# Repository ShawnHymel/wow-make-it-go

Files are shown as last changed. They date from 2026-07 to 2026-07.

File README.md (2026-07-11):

# WOW Make It Go

Pinewood derby style track timer for the "Make It Go" exhibit at the [WOW Children's Museum](https://wowchildrensmuseum.org/).

## Hardware

Each track uses its own full setup (i.e. separate Arduino, sensors, etc.). The track timers do not talk to each other. Each track requires:

 * [Arduino UNO R3](https://store-usa.arduino.cc/products/arduino-uno-rev3) or [SparkFun RedBoard](https://www.sparkfun.com/sparkfun-redboard-programmed-with-arduino.html)
 * [SparkFun Qwiic Shield](https://www.sparkfun.com/catalogsearch/result/?q=proto+shield)
 * 2x [SparkFun Proximity Sensor Breakout](https://www.sparkfun.com/sparkfun-proximity-sensor-breakout-20cm-vcnl4040-qwiic.html)
 * [SparkFun 7-Segment Serial Display - Red](https://www.sparkfun.com/sparkfun-7-segment-serial-display-red.html)
 * 2x [SparkFun QwiicBus EndPoint](https://www.sparkfun.com/sparkfun-qwiicbus-endpoint.html)
 * 2x [RJ45 Female Connector Breakout](https://www.amazon.com/Cermant-RJ45-Single-Connector-Interface/dp/B0D7ZZQ8CJ/)
 * [CAT6 Patch Cable 15 ft](https://www.amazon.com/Amazon-Basics-Ethernet-High-Speed-Snagless/dp/B089MGH8W3/)
 * [CAT6 Patch Cable 6 ft](https://www.amazon.com/Cable-Matters-Ethernet-Patch-Black/dp/B0CP9XGZKM/)
 * USB Cable 15 ft ([Type-B](https://www.amazon.com/Monoprice-15-Feet-24AWG-Plated-105440/dp/B003L11CRU/) for UNO R3, [Mini-B](https://www.amazon.com/Monoprice-15-Feet-Mini-B-Ferrite-105450/dp/B002KL8N6A/) for RedBoard)
 * [USB power adapter](https://www.amazon.com/Charger-Adapter-Charging-Station-Samsung/dp/B08139YF93/)

## Connections

TODO: fill this out. For now, refer to the connections in the Arduino sketch

## Programming

Load the [track_timer](software\track_timer\track_timer.ino) sketch in Arduino. Upload it to the Arduino board.

## License

All software in this repository, unless otherwise noted, is licensed under the [Zero-Clause BSD](https://opensource.org/license/0bsd) license.

```
Permission to use, copy, modify, and/or distribute this software for
any purpose with or without fee is hereby granted.

THE SOFTWARE IS PROVIDED “AS IS” AND THE AUTHOR DISCLAIMS ALL
WARRANTIES WITH REGARD TO THIS SOFTWARE INCLUDING ALL IMPLIED WARRANTIES
OF MERCHANTABILITY AND FITNESS. IN NO EVENT SHALL THE AUTHOR BE LIABLE
FOR ANY SPECIAL, DIRECT, INDIRECT, OR CONSEQUENTIAL DAMAGES OR ANY
DAMAGES WHATSOEVER RESULTING FROM LOSS OF USE, DATA OR PROFITS, WHETHER IN
AN ACTION OF CONTRACT, NEGLIGENCE OR OTHER TORTIOUS ACTION, ARISING OUT
OF OR IN CONNECTION WITH THE USE OR PERFORMANCE OF THIS SOFTWARE.
```

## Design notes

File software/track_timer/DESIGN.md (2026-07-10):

# Track Timer — design notes

Non-blocking gravity-track timer: an object rests on a start gate (sensor 1),
is released, rolls, and trips a finish line (sensor 2). Two VCNL4040 proximity
sensors, one SparkFun serial 4-digit 7-segment display.

## Display format

`SSS.C` — seconds with one tenth (decimal point after digit 3, `DP3`).
The ones-of-seconds digit is always drawn, so zero reads `0.0`, not `.0`.
Range spans to 999.9 s, which is also the timeout ceiling below.

## Sensing

Neither sensor has a fixed trigger level. `setup()` averages
`AMBIENT_SAMPLES` (10) readings from each sensor with the track clear, stores
them as `ambient1` / `ambient2`, and thereafter treats
`ambient + TRIGGER_DELTA` (500) as "covered". This is why the track must be
empty at boot.

`checkTrigger()` applies 50 counts of hysteresis: a sensor that has fired
re-arms only once its reading falls back below `threshold - 50`, so a hovering
hand cannot machine-gun triggers.

## State machine

Everything is driven by `millis()` and the sensors' own edge/level state —
no `delay()`, no blocking.

| State | Display | Exit condition | Next |
|---|---|---|---|
| `READY` | `0.0` at boot, else last result  | object placed on gate (sensor 1 rising edge) | `PRIMED` |
| `PRIMED` | steady `-GO-` | object leaves gate (sensor 1 falling edge) | `RUNNING`  |
| `RUNNING`  | live time | finish line (sensor 2 rising edge) | `FINISHED` |
| `RUNNING`  | live time | 999.9 s timeout | `READY` |
| `FINISHED` | final time, flashing then held | `FINISH_FLASH_COUNT` flashes elapsed | `READY` |
| `ERROR` | `Err1` / `Err2` | both sensors read OK again | `READY` |

- `READY` doubles as the post-race state: the final time stays frozen on the
  display until a new object re-primes the gate (that is the "reset").
- `FINISHED` blinks the result `FINISH_FLASH_COUNT` (4) times, toggling every
  `FINISH_FLASH_MS` (300 ms) and starting from blank — about 2.4 s — then holds
  the time and drops to `READY`.
- A sensor 1 rising edge re-primes from **any** state except `ERROR`, not just
  from `READY`. Re-staging an object on the gate mid-race abandons the run in
  progress rather than waiting for the timeout.
- Timeout freezes the display at the 999.9 s ceiling and returns to `READY`;
  it is not treated as an error and does not flash.

### Both sensors are polled every pass

`loop()` calls `checkTrigger()` on both sensors unconditionally — that call is
what refreshes each sensor's `ok()` and `covered()` state, so it cannot be
skipped. What is state-dependent is whether the returned edge is *consumed*:
sensor 2's rising edge is only acted on in `RUNNING`.

An edge raised outside `RUNNING` is therefore discarded, and — because of the
hysteresis above — that sensor stays latched `covered` until it re-arms. An
object left sitting on the finish line before the race starts will not produce
a finish trigger when the race runs; it has to be lifted clear first.

### Errors

A failed read on either sensor (`READ_ERROR` = `0xFFFF`) puts the machine in
`ERROR` immediately, from any state, and `loop()` returns early. Recovery — one
pass where both sensors read cleanly — resets to `READY` and clears the display
to `0.0`, so an error mid-race loses that run's time. `prevCovered1` is
resynced on the way out so the recovery does not fire a phantom release edge.

`ERROR_REBOOT_LIMIT` (10) *consecutive* failed passes on either sensor calls
`hardReboot()`. The per-sensor counters reset on any fully clean pass. Note
that a pass costs single-digit milliseconds, so ten of them go by fast: in
practice `Err1` / `Err2` flickers rather than sits on the display before the
reboot. Raise the limit if you want the code readable by a human on the bench.

`hardReboot()` arms the watchdog at its shortest timeout (15 ms) and spins,
which resets registers and peripherals too — unlike a jump-to-zero soft reset.

## Watchdog

`wdt_enable(WDTO_1S)` at the end of `setup()`, `wdt_reset()` at the top of
`loop()`. Three things about the placement are load-bearing:

- **Armed last, not first.** `setup()` blocks for >2 s (two settle delays plus
  `AMBIENT_SAMPLES * 50 ms` of calibration). Arming before that resets us
  mid-calibration, forever.
- **Fed at the top of `loop()`, not the bottom.** The `ERROR` branch `return`s
  early. A feed at the bottom would be skipped on every failed read, letting
  the watchdog pre-empt the `ERROR_REBOOT_LIMIT` path that is supposed to own
  that reboot (and its `Err1` / `Err2` display).
- **`MCUSR` / `WDRF` cleared first.** After a watchdog reset the WDT is still
  armed; `WDRF` must be cleared before `WDE` can be. Optiboot does this before
  handing over — ours is belt-and-braces, and would not save a stock bootloader
  (that one gets reset inside its own startup delay, before `setup()` runs).

It exists to catch one thing the `ERROR` state cannot. The AVR `Wire` library
spins with **no timeout** in `endTransmission()` / `requestFrom()`, so a
finish-line VCNL4040 that wedges SDA low hangs `loop()` forever, with no failed
read to count. This is accepted as-is rather than fixed in the driver: it is
unlikely, and a bounded TWI implementation is a lot of code to own. The
watchdog is the cheap backstop.

`SoftVCNL4040::sclHighWait()` already bounds its own spin at 1000 µs, so the
bit-banged start gate degrades into `READ_ERROR` and the `ERROR` state instead
of hanging — it never needed the watchdog.

`hardReboot()` is unaffected: `wdt_enable()` performs the WDCE/WDE timed
sequence, so re-arming a running 1 s watchdog down to 15 ms is legal.

## Bus layout

Both VCNL4040s answer to I2C address `0x60`, so they can't share a bus.
Each sensor gets its own:

- **Sensor 1 (start gate)** — bit-banged software I2C (`SoftVCNL4040`) on
  SDA pin 2 / SCL pin 5.
- **Sensor 2 (finish line)** — hardware I2C (`HardVCNL4040`, the `Wire`
  library) on the ATmega's fixed TWI pins A4 (SDA) / A5 (SCL).

Both drivers expose the same API (`begin` / `checkTrigger` / `ok` / `covered` /
`last`), so the state machine treats the two sensors identically.

The VCNL4040 is a 3.3 V part and both breakouts carry 2.2 kΩ pull-ups to 3.3 V,
so neither driver may enable the AVR's internal pull-ups. `SoftVCNL4040`
emulates open-drain by hand (drive low, or release to float).
`HardVCNL4040::begin()` has to actively switch them back off, because
`Wire.begin()` turns them on.

## Driver support (`SoftVCNL4040.h` / `HardVCNL4040.h`)

Three small additions so the sketch can see gate edges and read failures:

- `checkTrigger()` ignores a failed read (`READ_ERROR` = `0xFFFF`) instead of
  treating it as a huge value and firing a phantom trigger.
- `covered()` — debounced presence level, used to detect the *release*
  (falling) edge of the start gate.
- `ok()` — `_last != READ_ERROR`, drives the `ERROR` state.

## Display driver (`Serial7Seg.h`)

Unchanged. The sketch only pushes over SPI when the shown content changes:
`showTenths()` caches the last numeric value, `showText()` handles
`-GO-` / errors / blank, and `showMode` tracks which of the two is on screen so
the decimal point is toggled only on an actual number↔text transition.

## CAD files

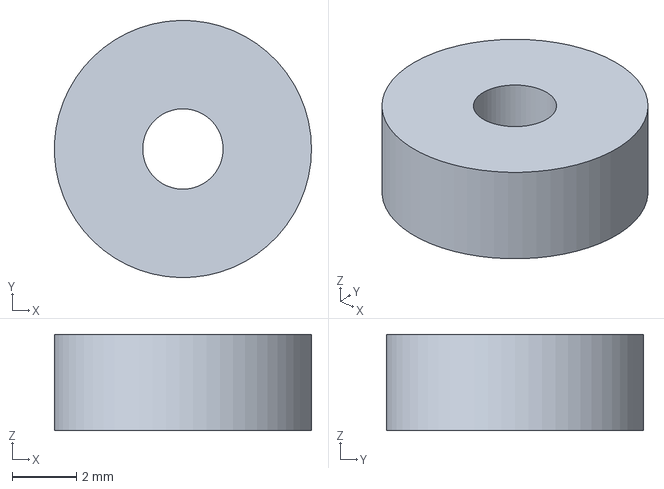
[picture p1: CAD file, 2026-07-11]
mechanical/prox-sensor-washer.FCStd
7.99 x 8.00 x 3.00 mm

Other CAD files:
mechanical/prox-sensor-washer.stl

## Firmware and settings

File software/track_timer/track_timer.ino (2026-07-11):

// Arduino libraries
#include <SPI.h>
#include <avr/wdt.h>

// Custom libraries
#include "SoftVCNL4040.h"
#include "HardVCNL4040.h"
#include "Serial7Seg.h"

//*****************************************************************************
// Settings

// Set to 1 to stream both sensors' raw readings over serial every loop pass.
// Leave at 0 for normal operation.
#define DEBUG 0

const uint16_t TRIGGER_DELTA     = 500;   // how far above ambient = "covered"
const uint8_t  AMBIENT_SAMPLES   = 10;    // readings to average during calibration

const uint8_t  DISPLAY_SS_PIN    = 8;
const uint8_t  DISPLAY_BRIGHTNESS = 255;

// A run that never trips the finish line is abandoned here. The timer
// freezes at the ceiling and the display returns to READY.
const unsigned long RACE_TIMEOUT_MS = 999900UL;   // 999.9 s

// Finish-line time flash: blink the result this many times before holding.
const uint8_t      FINISH_FLASH_COUNT = 4;
const unsigned long FINISH_FLASH_MS   = 300UL;

// Consecutive read failures before a hard reboot.
const uint8_t ERROR_REBOOT_LIMIT = 10;

// Watchdog timeout. A normal loop() pass is a few milliseconds -- two sensor
// reads and at most one SPI write -- so a second leaves enormous headroom
// while still recovering faster than a spectator can register the freeze.
const uint8_t WDT_TIMEOUT = WDTO_1S;

//*****************************************************************************
// Globals

// Both VCNL4040s answer to I2C address 0x60, so they can't share a bus.
// We split them across two buses instead: the start gate is bit-banged on
// its own SDA/SCL pins, and the finish line owns the ATmega's dedicated
// hardware-I2C pins (A4 = SDA, A5 = SCL). One sensor per bus, no clash.
SoftVCNL4040 prox1(2, 5);  // bit-banged SDA 2 / SCL 5 -- start gate
HardVCNL4040 prox2;         // hardware I2C on A4/A5    -- finish line

// 7-segment LED display
Serial7Seg display(DISPLAY_SS_PIN);

// Proximity sensor ambient baselines (captured during setup)
uint16_t ambient1 = 0;
uint16_t ambient2 = 0;


//*****************************************************************************
// Timer state machine
//
//   READY    -- idle. Display holds 0.0 (boot) or the last race time until a
//               new object is placed on the start gate.
//   PRIMED   -- object resting on the gate. Show steady "GO" until released.
//   RUNNING  -- object has left the gate; count up live. Stop on the finish
//               line (sensor 2) or at the timeout ceiling.
//   FINISHED -- finish line tripped; flash the final time a few times, then
//               hold it and return to READY.
//   ERROR    -- a sensor read failed; show Err1/Err2 until it recovers.
//
// Nothing here blocks: every transition is driven by millis() and the
// sensors' own edge/level state.

enum State { READY, PRIMED, RUNNING, FINISHED, ERROR };

//*****************************************************************************
// Display helpers
//
// The display keeps whatever it was last sent, so we only push over SPI
// when the shown content actually changes. showMode tracks whether the
// display is currently rendering a number (with the SSS.C decimal point)
// or free text (GO / errors / blank), so we know when to toggle the
// decimal point and when a cached numeric value is still valid.

enum ShowMode { SHOW_NONE, SHOW_NUM, SHOW_TEXT };
ShowMode showMode = SHOW_NONE;

// Show a time as SSS.C (seconds with one tenth). The ones-of-seconds
// digit is always drawn, so zero reads as "0.0" rather than ".0".
void showTenths(unsigned long tenths) {
  static long lastNum = -1;
  if (showMode != SHOW_NUM) {
    display.setDecimals(Serial7Seg::DP3);   // decimal point after digit 3
    showMode = SHOW_NUM;
    lastNum = -1;                            // force a redraw after text
  }
  if ((long)tenths == lastNum) return;
  lastNum = (long)tenths;

  char buf[8];
  snprintf(buf, sizeof(buf), "%3lu%1lu", tenths / 10, tenths % 10);
  display.print(buf);
}

// Show up to four characters with the decimal point off. Called only on
// state changes and blink toggles, so it just resends every time.
void showText(const char* s) {
  if (showMode != SHOW_TEXT) {
    display.setDecimals(0);
    showMode = SHOW_TEXT;
  }
  display.print(s);
}

//*****************************************************************************
// Functions

// Force a full hardware reset. Arming the watchdog for its shortest timeout
// and spinning lets it fire, which resets the whole MCU (registers,
// peripherals and all) -- unlike a jump-to-zero soft reset. Give the serial
// line a moment to flush the message first.
void hardReboot() {
  Serial.flush();
  wdt_enable(WDTO_15MS);
  while (1) { }
}

// Read N samples from each sensor and store the average as the ambient
// baseline. Called once during setup after both sensors are initialised.
void calibrateAmbient() {
  uint32_t sum1 = 0, sum2 = 0;
  for (uint8_t i = 0; i < AMBIENT_SAMPLES; i++) {
    sum1 += prox1.readProximity();
    sum2 += prox2.readProximity();
    delay(50);
  }
  ambient1 = sum1 / AMBIENT_SAMPLES;
  ambient2 = sum2 / AMBIENT_SAMPLES;

  Serial.print(F("Ambient 1: ")); Serial.println(ambient1);
  Serial.print(F("Ambient 2: ")); Serial.println(ambient2);
}

// Re-baseline a sensor: average a short burst of readings and return it as
// the new ambient level. Call this only when the sensor is known to be clear
// (finish line at race start, start gate at race end). Unlike
// calibrateAmbient() there is NO inter-sample delay -- the burst is ~1 ms, so
// it is safe to call mid-race without blocking finish detection or the clock.
template <typename T>
uint16_t burstAmbient(T &sensor) {
  uint32_t sum = 0;
  for (uint8_t i = 0; i < AMBIENT_SAMPLES; i++) sum += sensor.readProximity();
  return sum / AMBIENT_SAMPLES;
}

// Re-baseline the start gate at the end of a race, when the car has left the
// gate and it should be reading clear. Skipped if something is already on the
// gate (a runner re-staging the instant the race ends), so an object is never
// captured as the baseline -- the previous good baseline just stands.
void rebaselineStartGate() {
  if (!prox1.covered()) ambient1 = burstAmbient(prox1);
}

void reportTrigger(uint8_t lane, uint16_t reading) {
  Serial.print(F("TRIGGER lane "));
  Serial.print(lane);
  Serial.print(F(" @ "));
  Serial.print(millis());
  Serial.print(F(" ms  (reading: "));
  Serial.print(reading);
  Serial.println(')');
}

//*****************************************************************************
// Main

void setup() {

  // Disarm the watchdog before anything else. Coming out of a watchdog reset
  // the WDT is still armed at the timeout that fired it, and WDRF must be
  // cleared before WDE can be -- clearing WDE alone is a silent no-op.
  // Optiboot already does this before handing us control (which is why the
  // existing hardReboot() recovers instead of bricking the board); this is
  // belt-and-braces, and it will NOT rescue a stock bootloader -- that one
  // gets reset inside its own startup delay, long before setup() runs.
  MCUSR &= ~_BV(WDRF);
  wdt_disable();

  // Pour a bowl of serial
  Serial.begin(115200);

  // Initialize the display
  Serial.println(F("Initializing display..."));
  display.begin();
  display.clear();
  display.setBrightness(DISPLAY_BRIGHTNESS);

  // Initialize start proximity sensor
  Serial.println(F("Initializing proximity sensor 1..."));
  delay(1000);
  bool ok1 = prox1.begin();
  if (!ok1) {
    Serial.println(F("Error: Sensor 1 not found"));
    showText("Err1");
    delay(1000);
    hardReboot();
  }

  // Initialize finish proximity sensor
  Serial.println(F("Initializing proximity sensor 2..."));
  delay(1000);
  bool ok2 = prox2.begin();
  if (!ok2) {
    Serial.println(F("Error: Sensor 2 not found"));
    showText("Err2");
    delay(1000);
    hardReboot();
  }

  // Capture ambient proximity baselines before anything is on the track.
  Serial.println(F("Both sensors armed. Calibrating..."));
  calibrateAmbient();

  // Timer starts at 0.0, waiting for an object on the gate.
  showTenths(0);

  // Arm the watchdog last. Everything above blocks for well over two seconds
  // (two settle delays plus AMBIENT_SAMPLES * 50 ms of calibration), so any
  // timeout short enough to be useful in loop() would reset us mid-setup.
  Serial.println(F("Enabling watchdog timer..."));
  wdt_enable(WDT_TIMEOUT);

  // Say we've booted
  Serial.println(F("Boot complete. Running!"));
}

void loop() {
  static State state = READY;
  static unsigned long startTime    = 0;   // millis() when the gate released
  static unsigned long finishTenths = 0;   // cached finish time for flashing
  static unsigned long flashClock   = 0;   // last finish blink toggle
  static uint8_t       flashesLeft  = 0;   // remaining finish blinks
  static bool          flashOn      = false;
  static bool          prevCovered1 = false;

  // Feed the dog at the TOP of loop(), not the bottom: the error branch below
  // returns early, and a feed at the bottom would be skipped on every failed
  // read -- handing the watchdog a reboot that ERROR_REBOOT_LIMIT already owns.
  wdt_reset();

  // Poll both sensors once per pass. checkTrigger() also refreshes each
  // sensor's ok()/covered() state.
  bool rise1 = prox1.checkTrigger(ambient1 + TRIGGER_DELTA);   // object arrived at gate
  bool rise2 = prox2.checkTrigger(ambient2 + TRIGGER_DELTA);   // object hit finish line

#if DEBUG
  // Raw readings from this pass (last() is the value checkTrigger just read;
  // 65535 = read error). Printed before the error branch so failing reads
  // still show up.
  Serial.print(F("prox1: "));
  Serial.print(prox1.last());
  Serial.print(F("\tprox2: "));
  Serial.println(prox2.last());
#endif

  // A bad read trumps everything: show the error and skip the rest of
  // loop() until the sensor recovers. Reboot after too many in a row.
  static uint8_t errCount1 = 0;
  static uint8_t errCount2 = 0;

  bool fail1 = !prox1.ok();
  bool fail2 = !prox2.ok();

  // Error recovery for sensors: show error code and reboot if the error occurs
  // too many times.
  if (fail1 || fail2) {
    if (fail1) {
      errCount1++;
      Serial.print(F("Error: sensor 1 ("));
      Serial.print(errCount1);
      Serial.println(')');
    }
    if (fail2) {
      errCount2++;
      Serial.print(F("Error: sensor 2 ("));
      Serial.print(errCount2);
      Serial.println(')');
    }
    // Show whichever sensor is failing (prefer Err1 if both)
    showText(fail1 ? "Err1" : "Err2");
    state = ERROR;

    if (errCount1 >= ERROR_REBOOT_LIMIT || errCount2 >= ERROR_REBOOT_LIMIT) {
      Serial.println(F("Too many consecutive errors -- rebooting"));
      hardReboot();
    }
    return;   // skip the rest of loop() until next pass
  }

  // Both sensors read OK this pass.
  if (state == ERROR) {
    errCount1 = 0;
    errCount2 = 0;
    state = READY;
    prevCovered1 = prox1.covered();  // resync so we don't fire a phantom edge
    showTenths(0);
  }
  errCount1 = 0;
  errCount2 = 0;

  // Falling edge on the start gate = the object was released.
  bool covered1 = prox1.covered();
  bool release1 = prevCovered1 && !covered1;
  prevCovered1 = covered1;

  // A rising edge on the start gate always primes, regardless of state.
  // This lets a runner re-stage mid-race without waiting for a timeout.
  if (rise1 && state != PRIMED) {
    reportTrigger(1, prox1.last());
    Serial.println(F("PRIMED -- GO"));
    state = PRIMED;
    display.clear();
    showText("-GO-");
  }

  switch (state) {

    case READY:
      break;   // waiting for rise1, handled above

    case PRIMED:
      if (release1) {
        Serial.println(F("START"));
        state = RUNNING;
        startTime = millis();
        // The finish line is guaranteed clear right now (the car is still at
        // the gate), so re-capture its baseline and re-arm. This corrects a
        // baseline that drifted too far below the resting level to self-heal
        // -- otherwise the first crossing either never registers (stale latch)
        // or fires instantly (resting sits above threshold) -- and guarantees
        // a fresh rising edge for the first real crossing of this run.
        //
        ambient2 = burstAmbient(prox2);
        prox2.rearm();
        display.clear();
        showTenths(0);
      }
      break;

    case RUNNING: {
      unsigned long elapsed = millis() - startTime;
      bool timedOut = elapsed >= RACE_TIMEOUT_MS;
      if (timedOut) elapsed = RACE_TIMEOUT_MS;   // clamp to the ceiling
      showTenths(elapsed / 100);

      if (rise2) {
        reportTrigger(2, prox2.last());
        Serial.print(F("FINISH @ "));
        Serial.print(elapsed / 1000.0, 1);
        Serial.println(F(" s"));
        finishTenths = elapsed / 100;
        flashClock   = millis();
        flashesLeft  = FINISH_FLASH_COUNT;
        flashOn      = false;              // start with blank (first toggle shows time)
        showText("    ");
        state = FINISHED;
      } else if (timedOut) {
        Serial.print(F("TIMEOUT @ "));
        Serial.print(elapsed / 1000.0, 1);
        Serial.println(F(" s"));
        rebaselineStartGate();             // race over, gate clear -- refresh
        state = READY;                     // hold steady, no flash
      }
      break;
    }

    case FINISHED:
      if (flashesLeft > 0) {
        if (millis() - flashClock >= FINISH_FLASH_MS) {
          flashClock = millis();
          flashOn = !flashOn;
          if (flashOn) {
            showTenths(finishTenths);
          } else {
            showText("    ");
            flashesLeft--;
          }
        }
      } else {
        showTenths(finishTenths);           // hold the final time
        rebaselineStartGate();              // race over, gate clear -- refresh
        state = READY;
      }
      break;

    case ERROR:
      break;   // handled above; here to keep the compiler happy
  }
}

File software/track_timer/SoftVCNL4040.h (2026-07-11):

#ifndef SOFT_VCNL4040_H
#define SOFT_VCNL4040_H

// SoftVCNL4040 -- bit-banged (software) I2C driver for the VCNL4040
// proximity sensor. Header-only: just drop this next to your sketch and
// #include "SoftVCNL4040.h".
//
// Target: Arduino Uno / SparkFun RedBoard (5V AVR)
//
// WIRING (Qwiic cable colors):
//   RED    -> 3.3V   (NOT 5V -- the VCNL4040 is a 3.3V part)
//   BLACK  -> GND
//   BLUE   -> sdaPin (any digital pin)
//   YELLOW -> sclPin (any digital pin)
//
// No external pull-up resistors needed: the SparkFun breakout has
// 2.2k pull-ups to 3.3V on board. This code emulates open-drain --
// pins are only ever driven LOW or released to float, and internal
// pull-ups are never enabled, so the bus never sees 5V.
//
// Because pins are arbitrary, you can run multiple VCNL4040s (which all
// share address 0x60) by giving each its own SDA pin. Point them at a
// shared SCL pin and talk to one at a time; the idle sensors just sit on
// their own floating SDA line. See the accompanying .ino for a
// two-sensor example.

#include <Arduino.h>

class SoftVCNL4040 {
public:
  SoftVCNL4040(uint8_t sdaPin, uint8_t sclPin) : _sda(sdaPin), _scl(sclPin) {}

  bool begin() {
    // Release both lines. digitalWrite(LOW) while in INPUT mode clears
    // the PORT bit, which (a) keeps the internal pull-up OFF and
    // (b) means switching to OUTPUT always drives LOW.
    pinMode(_sda, INPUT);
    pinMode(_scl, INPUT);
    digitalWrite(_sda, LOW);
    digitalWrite(_scl, LOW);
    tick();

    if (read16(REG_ID) != 0x0186) return false;  // sensor not found

    // PS_CONF1/2: duty 1/40, integration time 8T, sensor ON, 16-bit output
    //   LSB 0x0E = PS_IT(3:1)=111, PS_SD(0)=0
    //   MSB 0x08 = PS_HD(3)=1 (16-bit proximity data)
    write16(REG_PS_CONF12, 0x080E);

    // PS_CONF3/MS: defaults + LED current 200 mA (LED_I(2:0)=111 in MSB)
    write16(REG_PS_CONF3MS, 0x0700);

    return true;
  }

  // Raw 16-bit proximity reading. Also caches the value; see last().
  uint16_t readProximity() {
    _last = read16(REG_PS_DATA);
    return _last;
  }

  // Sentinel returned by the register reads on an I2C failure (NAK / no
  // sensor). Proximity data never legitimately reaches 0xFFFF with these
  // settings, so it doubles as an "is this reading trustworthy" flag.
  static constexpr uint16_t READ_ERROR = 0xFFFF;

  // The most recent value read by readProximity() or checkTrigger().
  uint16_t last() const { return _last; }

  // True if the last read succeeded. A loose Qwiic cable or dead sensor
  // makes read16() return READ_ERROR; callers use this to surface an
  // error instead of acting on garbage.
  bool ok() const { return _last != READ_ERROR; }

  // Current debounced presence state: true while an object is over the
  // sensor, false once it has pulled back past the re-arm threshold.
  // Lets callers detect the *falling* edge (object leaving) as well as
  // the rising edge that checkTrigger() returns.
  bool covered() const { return _covered; }

  // Force the debounce state back to "not covered" so the very next reading
  // above threshold counts as a fresh rising edge -- even if the sensor is
  // currently reading high. Used to clear a stale latch (e.g. re-arming the
  // finish sensor at the start of a new race) that would otherwise swallow
  // the next real crossing.
  void rearm() { _covered = false; }

  // Rising-edge trigger with hysteresis. Reads the sensor once (updating
  // last()) and returns true exactly once each time proximity crosses
  // above `threshold`. It re-arms only after the reading falls back below
  // (threshold - hysteresis), so a hovering hand won't machine-gun
  // triggers. This replaces the external covered1/covered2 bookkeeping --
  // each sensor now tracks its own state.
  //
  // A failed read (READ_ERROR) is never treated as a trigger and leaves
  // the covered state untouched -- otherwise 0xFFFF would read as "way
  // above threshold" and fire a phantom trigger. Check ok() to detect it.
  bool checkTrigger(uint16_t threshold, uint16_t hysteresis = 50) {
    uint16_t val = readProximity();
    if (val == READ_ERROR) return false;   // bad read -> hold state, no trigger
    uint16_t rearm = (hysteresis < threshold) ? (threshold - hysteresis) : 0;

    if (!_covered && val > threshold) {
      _covered = true;          // rising edge -> trigger!
      return true;
    }
    if (_covered && val < rearm) {
      _covered = false;         // falling edge -> re-arm
    }
    return false;
  }

private:
  // ---- VCNL4040 registers (each is 16 bits, little-endian) ----------
  static constexpr uint8_t VCNL4040_ADDR  = 0x60;
  static constexpr uint8_t REG_ALS_CONF   = 0x00;
  static constexpr uint8_t REG_PS_CONF12  = 0x03;  // PS_CONF1 (LSB) + PS_CONF2 (MSB)
  static constexpr uint8_t REG_PS_CONF3MS = 0x04;  // PS_CONF3 (LSB) + PS_MS   (MSB)
  static constexpr uint8_t REG_PS_DATA    = 0x08;
  static constexpr uint8_t REG_ID         = 0x0C;  // reads 0x0186

  uint8_t  _sda, _scl;
  uint16_t _last    = 0;
  bool     _covered = false;

  // ---- open-drain pin control ---------------------------------------
  void sdaRelease() { pinMode(_sda, INPUT);  }  // float -> pulled to 3.3V
  void sdaDrive()   { pinMode(_sda, OUTPUT); }  // drive LOW
  void sclRelease() { pinMode(_scl, INPUT);  }
  void sclDrive()   { pinMode(_scl, OUTPUT); }
  bool sdaRead()    { return digitalRead(_sda); }

  void tick() { delayMicroseconds(4); }  // ~50 kHz effective, plenty

  // Release SCL and wait for it to actually go high (clock stretching)
  void sclHighWait() {
    sclRelease();
    uint16_t timeout = 1000;
    while (!digitalRead(_scl) && --timeout) delayMicroseconds(1);
  }

  // ---- I2C primitives -----------------------------------------------
  void i2cStart() {           // SDA falls while SCL high
    sdaRelease(); sclHighWait(); tick();
    sdaDrive();   tick();
    sclDrive();   tick();
  }

  void i2cStop() {            // SDA rises while SCL high
    sdaDrive();   tick();
    sclHighWait(); tick();
    sdaRelease(); tick();
  }

  bool writeByte(uint8_t b) { // returns true if slave ACKed
    for (uint8_t i = 0; i < 8; i++) {
      (b & 0x80) ? sdaRelease() : sdaDrive();
      b <<= 1;
      tick();
      sclHighWait(); tick();
      sclDrive();
    }
    // ACK bit: release SDA, clock it, sample
    sdaRelease(); tick();
    sclHighWait();
    bool ack = !sdaRead();    // slave pulls low = ACK
    tick();
    sclDrive(); tick();
    return ack;
  }

  uint8_t readByte(bool ack) {
    uint8_t b = 0;
    sdaRelease();
    for (uint8_t i = 0; i < 8; i++) {
      tick();
      sclHighWait(); tick();
      b = (b << 1) | (sdaRead() ? 1 : 0);
      sclDrive();
    }
    // send ACK (pull low) or NACK (leave high)
    ack ? sdaDrive() : sdaRelease();
    tick();
    sclHighWait(); tick();
    sclDrive();
    sdaRelease(); tick();
    return b;
  }
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

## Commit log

2026-07-08 Initial commit. Bit-bang I2C test with 2 prox sensors
2026-07-08 Simple start test with display timer
2026-07-08 Add non-blocking state machine to track timer
    Replace the start-only loop with a four-state machine (READY/PRIMED/
    RUNNING/ERROR) driven entirely by millis() and sensor edges:
    - PRIMED flashes "GO" as a start-gate cue; release starts the timer
    - RUNNING counts up live, stops on the finish line or a 99.9s timeout
    - Final time stays frozen until a new object re-primes the gate
    - Display shows SSS.C (seconds.tenths); zero reads "0.0"
    - ERROR (Err1/Err2) surfaces a failed sensor read and auto-recovers
    Driver support in SoftVCNL4040.h: error-safe checkTrigger (ignores a
    0xFFFF read instead of firing a phantom trigger), plus covered() and
    ok() getters. Adds DESIGN.md.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
    [SoftVCNL4040.h, track_timer.ino]
2026-07-10 track_timer: hard-reboot on sensor init failure; document dual-bus layout
    Replace the while(1) hang on "Sensor N not found" with a watchdog-driven
    hard reset so the timer self-recovers when a sensor/wiring comes back.
    Add HardVCNL4040 (hardware-I2C finish-line driver) and document the
    two-bus layout in DESIGN.md.
    [track_timer.ino]
2026-07-10 Changed to ambient reading + offset for prox sensing. Steady GO, flash end time. Added auto-resets on sensor errors.
    [track_timer.ino]
2026-07-10 Added watchdog timer to sketch
2026-07-10 Fixed display function calls at boot
    [track_timer.ino]
2026-07-10 Add sensors_test_hwi2c sketch with hardware I2C VCNL4040 support
2026-07-11 Reorganized folders. Added README.
    [prox-sensor-washer.FCStd, prox-sensor-washer.stl]
